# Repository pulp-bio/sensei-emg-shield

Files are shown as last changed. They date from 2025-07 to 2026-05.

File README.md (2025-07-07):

# SENSEI EMG shield

This repository contains the hardware design files for the **SENSEI EMG shield**, a versatile and modular platform designed for Electromyography (EMG) signal acquisition.

## Overview

The **SENSEI EMG Shield** simplifies EMG measurements with a flexible electrode-to-channel mapping system. Different electrode configurations can be rapidly selected by plugging interchangeable channel mapping PCBs directly onto the shield, enabling quick adaptation to different measurement scenarios.

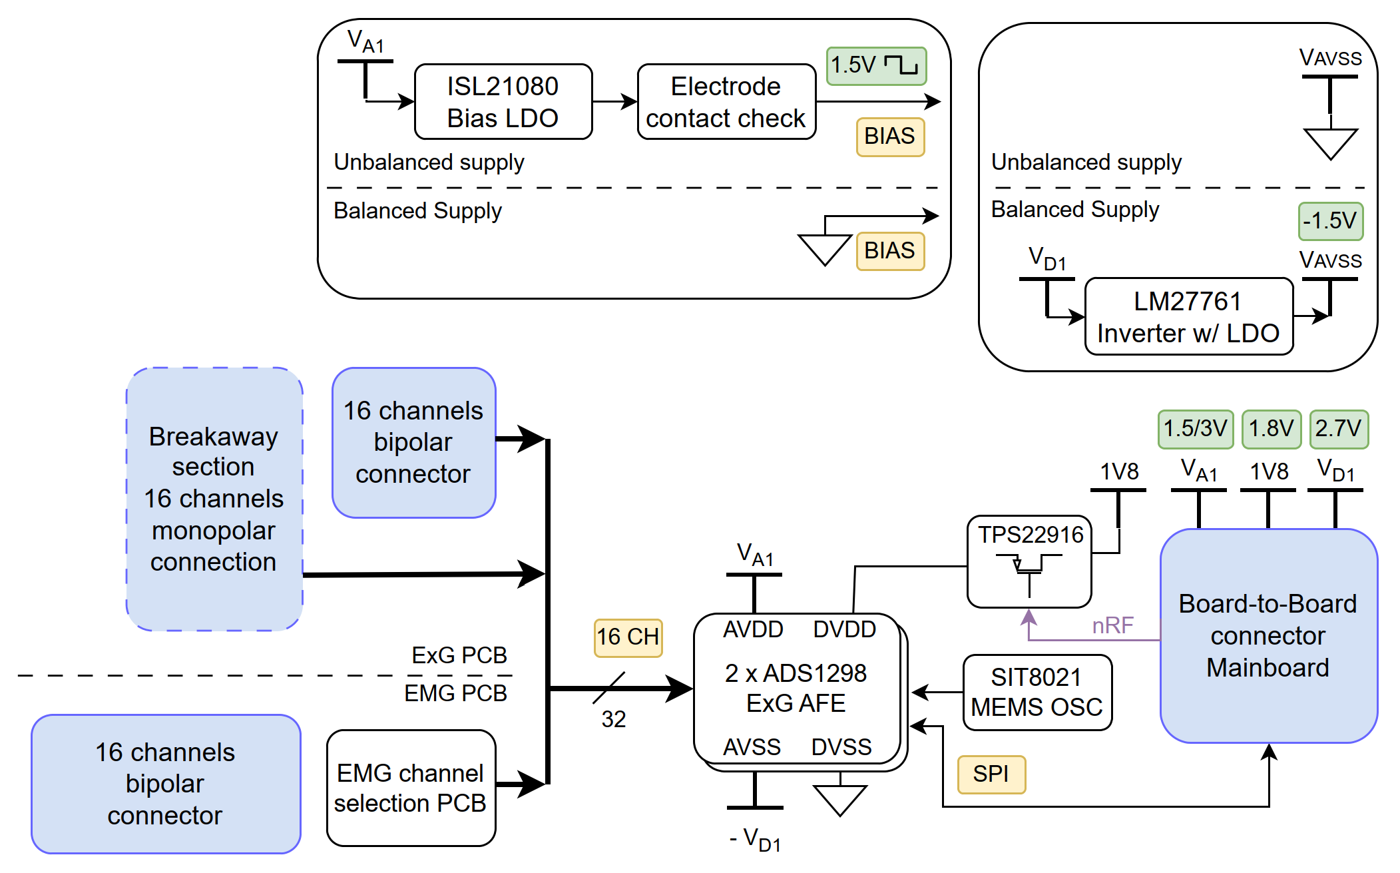
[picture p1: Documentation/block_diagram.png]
Block Diagram


### Key Features
- **16 EMG channels**
- Interchangeable electrode-to-channel mappings:
  - Fully differential
  - Partial electrode sharing
  - Common reference electrode montage
- Easy configuration through swappable channel-mapping PCBs
- Balanced (±1.5 V) analog operation
- Stable MEMS-based clock (±50 ppm accuracy)

## Changelog
A changelog is available in the [Changelog.md](Changelog.md) file, which tracks all major updates and revisions to the board's design and documentation.

## Contributors
- **Sebastian Frey** ([sefrey@iis.ee.ethz.ch](mailto:sefrey@iis.ee.ethz.ch))

## License
This repository makes use of the following licenses:
- for all *hardware*: Solderpad Hardware License Version 0.51
- for all *images*: Creative Commons Attribution 4.0 International
License][cc-by]

For further information have a look at the license files: `LICENSE.hw`, `LICENSE.images`

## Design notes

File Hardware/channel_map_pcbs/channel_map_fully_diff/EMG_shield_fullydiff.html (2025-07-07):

Altium customize

# Board Information Report

Date: | | 19/01/2025
Time: | | 16:14:43
Elapsed Time: | | 00:00:00
Filename: | | C:\Users\laksh\Desktop\BA\pcb\ExG_shield_fullydiff_pcb\EMG_shield_fullydiff.PcbDoc
Units: | | mmmils

## Contents

Contents

Board Specification

General

Routing

Routing Information

Layer Information

Layer Information

Drill Pairs

Copper Area

Copper Area

Board Holes

Non-Plated Hole Size

Plated Hole Size

Board Slots

Non-Plated Slot Size

Plated Slot Size

Board Square Holes

Non-Plated Square Hole Size

Plated Square Hole Size

Other

Top Layer Annular Ring Size

Mid Layer Annular Ring Size

Bottom Layer Annular Ring Size

Pad Solder Mask

Pad Paste Mask

Pad Pwr/Gnd Expansion

Pad Relief Conductor Width

Pad Relief Air Gap

Pad Relief Entries

Via Solder Mask

Via Pwr/Gnd Expansion

Track Width

Arc Line Width

Arc Radius

Arc Degrees

Text Height

Text Width

Net Track Width

Net Via Size

## Board Specification

General
Board Size | 19.5322mm x 19.5375mm
Components on board | 2

Back to top

## Routing

Routing Information
Routing completion | 100.00%
Connections | 40
Connections routed | 40
Connections remaining | 0

Back to top

## Layer Information

Layer | Arcs | Pads | Vias | Tracks | Texts | Fills | Regions | ComponentBodies
Top Layer | 0 | 90 | 0 | 289 | 0 | 0 | 7 | 0
SIG1 | 0 | 0 | 0 | 174 | 0 | 0 | 9 | 0
SIG2 | 0 | 0 | 0 | 93 | 0 | 0 | 7 | 0
Bottom Layer | 0 | 0 | 0 | 60 | 0 | 0 | 7 | 0
Mechanical 1 | 0 | 0 | 0 | 0 | 1 | 0 | 0 | 2
Top 3D Body | 0 | 0 | 0 | 0 | 0 | 0 | 0 | 0
Top Courtyard | 0 | 0 | 0 | 0 | 0 | 0 | 0 | 0
Top Assembly | 0 | 0 | 0 | 0 | 0 | 0 | 0 | 0
Mechanical 13 | 2 | 0 | 0 | 8 | 0 | 0 | 0 | 0
Mechanical 15 | 0 | 0 | 0 | 8 | 0 | 0 | 2 | 0
Top Component Center | 0 | 0 | 0 | 0 | 0 | 0 | 0 | 0
Bottom Assembly | 0 | 0 | 0 | 0 | 0 | 0 | 0 | 0
Bottom Courtyard | 0 | 0 | 0 | 0 | 0 | 0 | 0 | 0
Bottom 3D Body | 0 | 0 | 0 | 0 | 0 | 0 | 0 | 0
Bottom Component Center | 0 | 0 | 0 | 0 | 0 | 0 | 0 | 0
Top Overlay | 0 | 0 | 0 | 12 | 4 | 0 | 0 | 0
Board Layer Stack Bottom Overlay | 3 | 0 | 0 | 0 | 2 | 0 | 7 | 0
Top Paste | 0 | 0 | 0 | 0 | 0 | 0 | 0 | 0
Bottom Paste | 0 | 0 | 0 | 0 | 0 | 0 | 0 | 0
Top Solder | 0 | 0 | 0 | 0 | 0 | 0 | 0 | 0
Board Layer Stack Bottom Solder | 0 | 0 | 0 | 0 | 0 | 0 | 0 | 0
Drill Guide | 0 | 0 | 0 | 0 | 0 | 0 | 0 | 0
Keep-Out Layer | 0 | 0 | 0 | 0 | 0 | 0 | 0 | 0
Drill Drawing | 0 | 0 | 0 | 0 | 0 | 0 | 0 | 0
Multi-Layer | 0 | 0 | 60 | 0 | 0 | 0 | 1 | 0
Total | 5 | 90 | 60 | 644 | 7 | 0 | 40 | 2

Back to top

Drill Pairs | Vias
Top Layer - Bottom Layer | 60
Total | 60

Back to top

## Copper Area

Layer | Sq.In. | Sq.MM. | Percent of layer
Top Layer | 0.453 | 292.274 | 77%
SIG1 | 0.454 | 292.964 | 77%
SIG2 | 0.495 | 319.507 | 84%
Bottom Layer | 0.508 | 327.491 | 86%
Total | 1.91 | 1232.236

Back to top

## Board Holes

Non-Plated Hole Size | Pads | Vias
Total | 0 | 0

Back to top

Plated Hole Size | Pads | Vias
0mm | 90 | 0
0.2mm | 0 | 60
Total | 90 | 60

Back to top

## Board Slots

Non-Plated Slot Size / Length | Pads
Total | 0

Back to top

Plated Slot Size / Length | Pads
Total | 0

Back to top

## Board Square Holes

Non-Plated Square Hole Size | Pads
Total | 0

Back to top

Plated Square Hole Size | Pads
Total | 0

Back to top

## Other

Top Layer Annular Ring Size | Count
0.15mm | 60
Total | 60

Back to top

Mid Layer Annular Ring Size | Count
0.15mm | 60
Total | 60

Back to top

Bottom Layer Annular Ring Size | Count
0.15mm | 60
Total | 60

Back to top

Pad Solder Mask | Count
0mm | 90
Total | 90

Back to top

Pad Paste Mask | Count
0mm | 90
Total | 90

Back to top

Pad Pwr/Gnd Expansion | Count
0.1016mm | 90
Total | 90

Back to top

Pad Relief Conductor Width | Count
0.1016mm | 90
Total | 90

Back to top

Pad Relief Air Gap | Count
0.1016mm | 90
Total | 90

Back to top

Pad Relief Entries | Count
4 | 90
Total | 90

Back to top

Via Solder Mask | Count
0.075mm | 60
Total | 60

Back to top

Via Pwr/Gnd Expansion | Count
0.1016mm | 60
Total | 60

Back to top

Track Width | Count
0.0254mm | 8
0.1524mm | 20
0.2mm | 605
0.5mm | 11
Total | 644

Back to top

Arc Line Width | Count
0.1472mm | 2
0.1636mm | 1
0.508mm | 2
Total | 5

Back to top

Arc Radius | Count
0.0008mm | 3
0.381mm | 2
Total | 5

Back to top

Arc Degrees | Count
360 | 5
Total | 5

Back to top

Text Height | Count
1.2mm | 2
1.524mm | 5
Total | 7

Back to top

Text Width | Count
0.15mm | 1
0.254mm | 6
Total | 7

Back to top

Net Track Width | Count
0.1016mm | 37
Total | 37

Back to top

Net Via Size | Count
0.35mm | 37
Total | 37

Back to top

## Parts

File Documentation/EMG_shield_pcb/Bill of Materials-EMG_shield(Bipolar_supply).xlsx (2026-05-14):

Line # | Name | Description | Designator | Quantity | Comment
 | CL05A104KA5NNNC | Cap Ceramic 100nF 25V X5R ±10% SMD 0402 +85°C Paper T/R | C1, C3, C4, C7, C10, C15, C17, C18, C22, C25, C32, C33, C34, C40, C41 | 15
 | CL05A105KP5NNNC | Cap Ceramic 1uF 10V X5R ±10% SMD 0402 +85°C Paper T/R | C2, C5, C6, C9, C11, C12, C16, C19, C20, C24, C26, C27, C37, C39, C42 | 15
 | CL05A106MP8NUB8 | Cap Ceramic 10uF 10V X5R ±20% SMD 0402 +85°C Paper T/R | C8, C23, C31 | 3
 | 04025C102KAT2A-62 | General Purpose Ceramic Capacitor, 0402, 1nF, 10%, X7R, 15%, 50V | C13, C28 | 2
 | CL05A226MQ5QUNC | Cap Ceramic 22uF 6.3V X5R ±20% SMD 0402 +85°C Paper T/R | C14, C29 | 2
 | GRM155R71H152KA01D |  | C21 | 1
 | CGA2B3X7R1V103K050BB | Cap Ceramic 10nF 35V X7R 10% Pad SMD 0402 +125°C Automotive T/R | C30 | 1
 | GRM155Z71A225KE01D | Chip Multilayer Ceramic Capacitors for General Purpose, 0402, 2.2uF, X7R, 15%, 10%, 10V | C35 | 1
 | CL05A475MP5NRNC | Cap Ceramic 4.7uF 10V X5R ±20% SMD 0402 +85°C Paper T/R | C36, C38 | 2
 | DF40HC(2.5)-40DS-0.4V(51) | 40 Position 0.4mm Pitch Dual Row Vertical Surface Mount (SMT) Pin Socket, 2.5mm Stacking Height | J3 | 1
 | DF40HC(2.5)-50DS-0.4V(51) | 50 Position 0.4mm Pitch Dual Row Vertical Surface Mount (SMT) Pin Socket, 2.5mm Stacking Height | J4 | 1
 | DF40C-40DP-0.4V(51) | 50 Position 0.4mm Pitch Dual Row Vertical Surface Mount (SMT) Receptacle | J5, J25 | 2
 | DF40C-50DP-0.4V(51) | 50 Position 0.4mm Pitch Dual Row Vertical Surface Mount (SMT) Receptacle, | J6, J24 | 2
 | PMSS3906,115 | PNP Switching Transistor | Q1 | 1
 | MCS04020C1004FE000 | RES SMD 1M OHM 1% 1/10W 0402 | R1 | 1
 | RT0402BRD0745K3L | RES 45.3K OHM 1/16W .1% SMD 0402 | R2 | 1
 | RN73R1ETTP2003B25 | 200kΩ ±0.1% 0.063W, 1/16W Chip Resistor 0402 (1005 Metric) Moisture Resistant Thin Film | R3 | 1
 | RC0402FR-070RL | RES SMD 0 OHM JUMPER 1/16W 0402 | R4, R10, R11, R12, R13, R14, R33 | 7
 | RT0402FRE074K7L | RES 4.70K OHM 1/16W 1% SMD 0402 | R5 | 1
 | TNPW040214K2BEED | RES 14.2K OHM 1/16W 1% SMD 0402 | R6 | 1
 | RT0402BRD076K34L | RES 6.34K OHM 1/16W 1% SMD 0402 | R7 | 1
 | RR0510P-563-D | 56kΩ ±0.5% 0.0625W 1/16W Chip Resistor 0402 (1005 Metric) Thin Film | R8 | 1
 | ADS1298RIZXGT | 8-Channel, 24-Bit ADC with Integrated Respiration Impedance and ECG Front End, -40 to 85 degC, 64-pin BGA (ZXG64), Green (RoHS & no Sb/Br) | U1, U2 | 2
 | ISL21080CIH320Z-TK | IC VREF SERIES 0.3% SOT23-3 | U3 | 1
 | LM27761DSGT | IC REG CHARGE PUMP ADJ 8WSON | U4 | 1
 | TPS22916CYFPR | Integrated Circuit | U6 | 1
 | SIT8021AC-J3-18S-2.048000 | MEMS OSC 2.048MHZ LVCMOS | Y1 | 1 | We will send this part

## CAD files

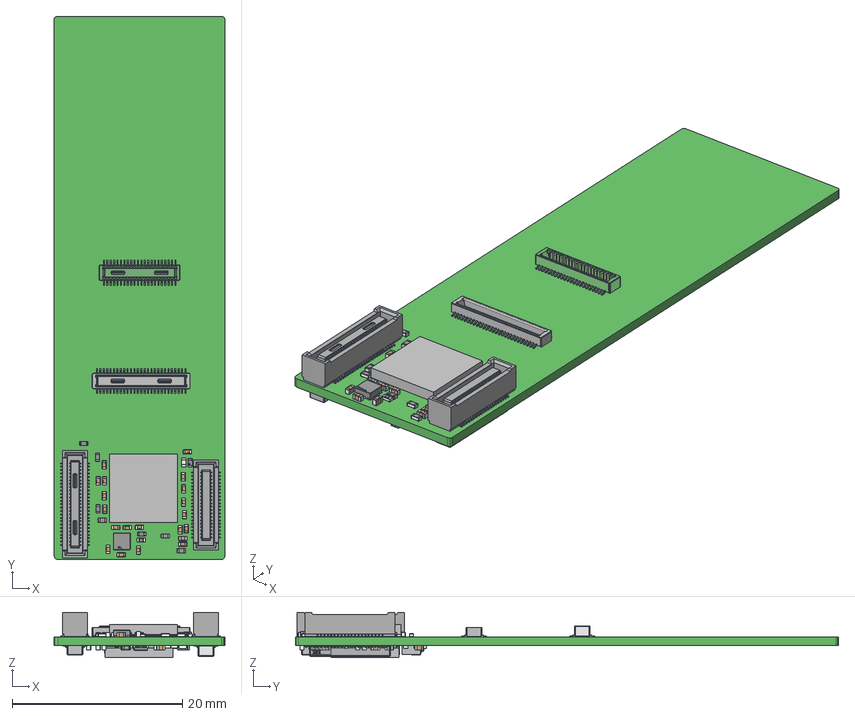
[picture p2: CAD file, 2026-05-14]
Documentation/EMG_shield_pcb/EMG_shield_3D_step.step
20.1 x 63.8 x 5.32 mm
Hirose Electric x 2
Extruded x 6
DF40C-50DP_RGB8421504 x 2
Yageo Logo x 7
terminals x 42
logo x 46
BODY-SON
FRAME-DSG0008A
Texas Logo Yury
Texas Logo Yury - Copy
Balls
0.1mm
Si Time Logo
IC_BODY
IC_LEG x 3
Renesas Logo
circle
Susumu Logo adjustable
pins x 4
top x 2
TDK Logo
DF40HC(3.0)-40DS-0.4V
DF40HC(3.0)-50DS

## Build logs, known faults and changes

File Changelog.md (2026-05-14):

# Changelog

## [1.0.1] (14.05.2026)

### Added

### Changed

- Clock source of ADS1298 is fixed to external oscillator
- Pin from board-to-board connector nRF_P0.05 is not used anymore for clk source selection

## [1.0.0] (03.07.2025)
- Inital version

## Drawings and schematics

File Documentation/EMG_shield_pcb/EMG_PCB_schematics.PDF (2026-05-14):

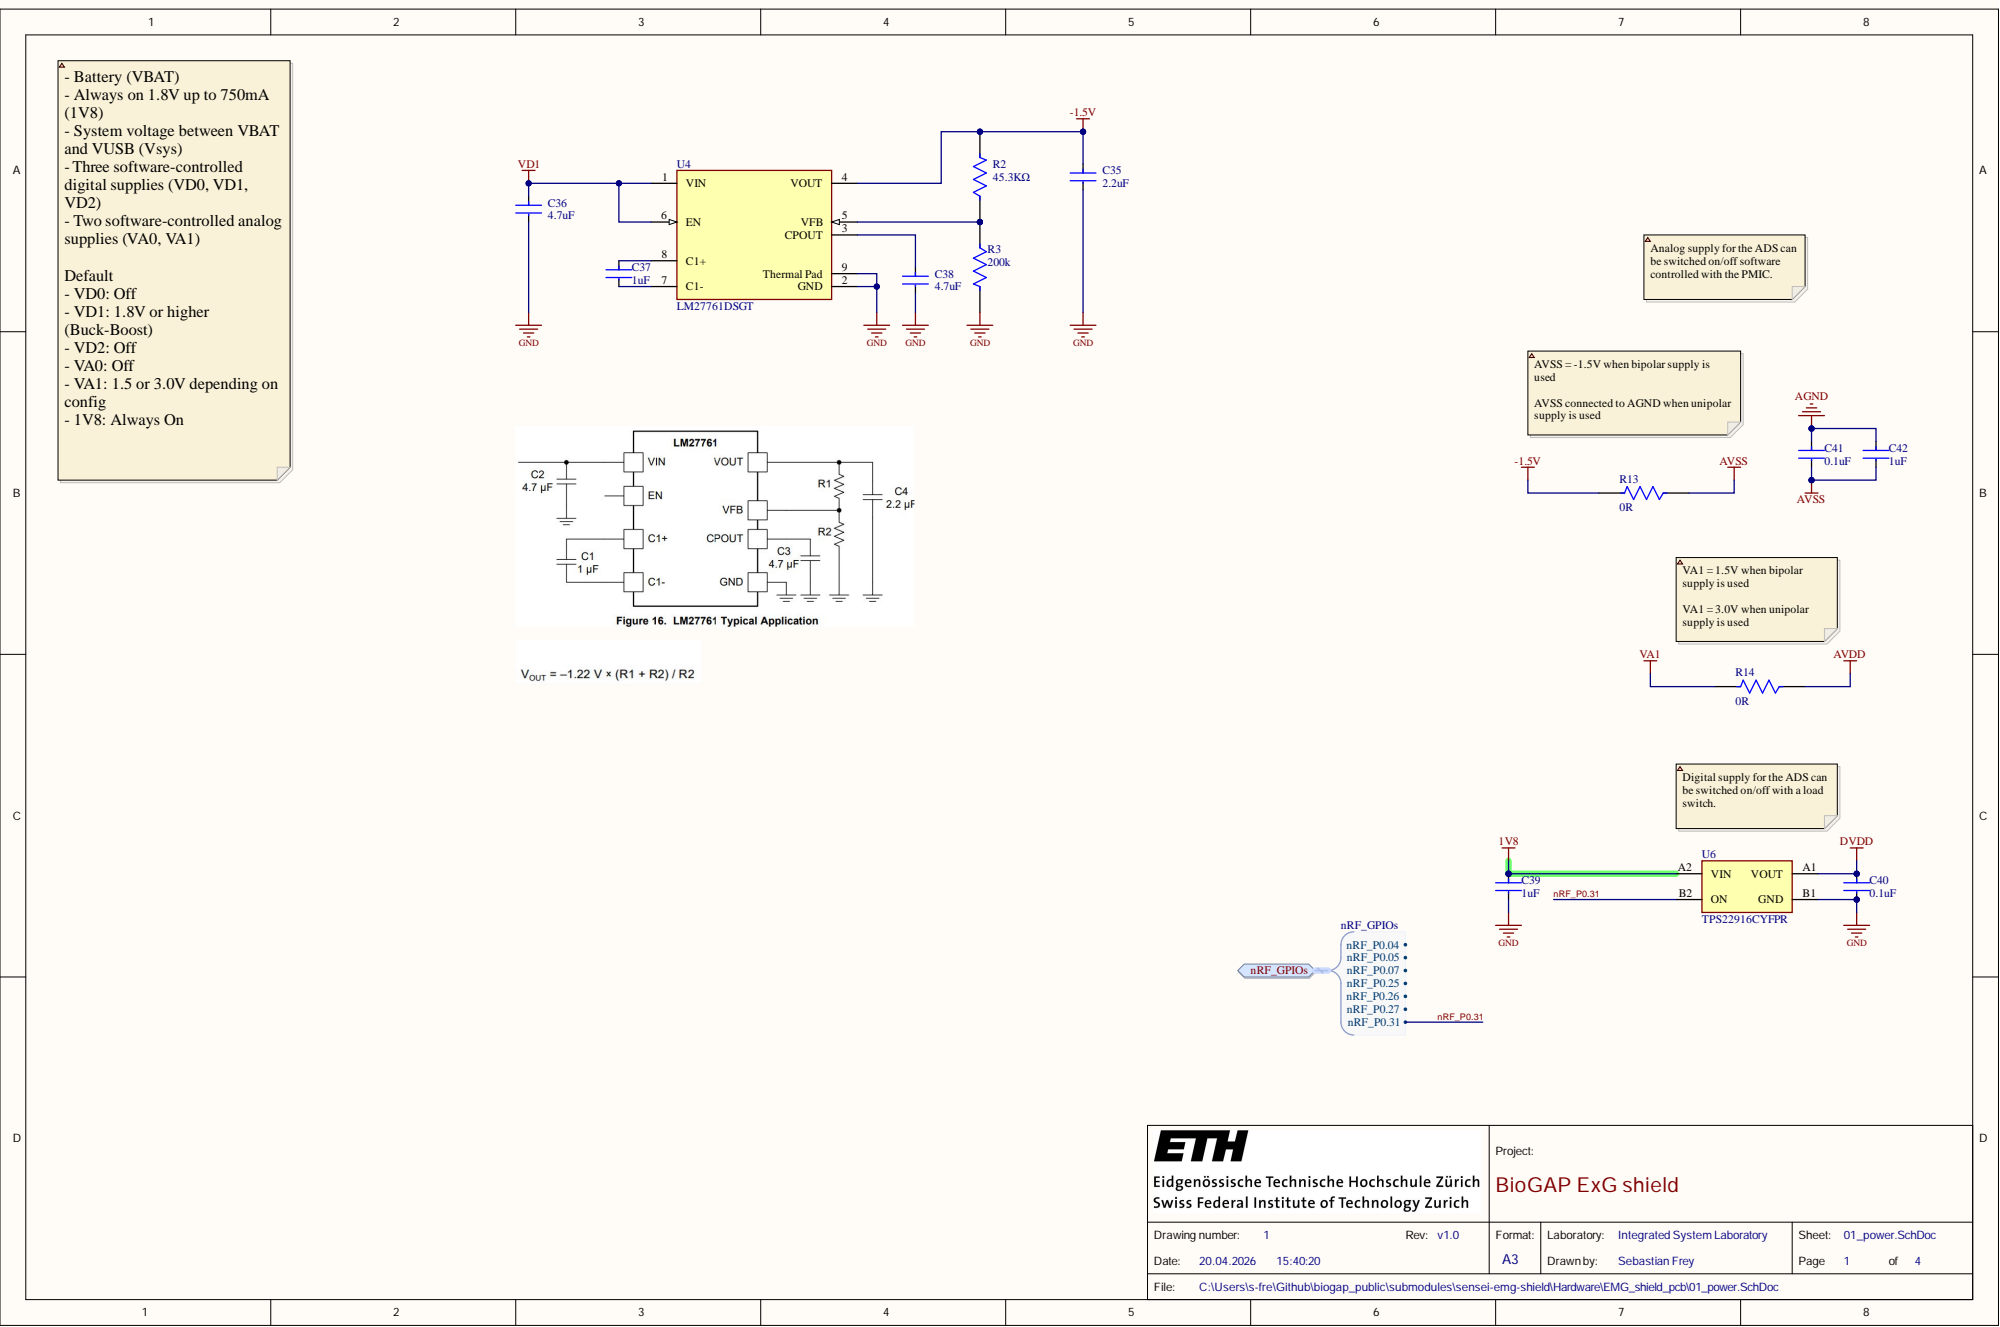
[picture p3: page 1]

- Battery (VBAT)
- Always on 1.8V up to 750mA
- System voltage between VBAT
and VUSB (Vsys)
- Three software-controlled
digital supplies (VD0, VD1,
- Two software-controlled analog
supplies (VA0, VA1)

Analog supply for the ADS can
be switched on/off software
controlled with the PMIC.

AVSS = -1.5V when bipolar supply is
used

AVSS connected to AGND when unipolar
supply is used

Digitalsupply for the ADS can
be switched on/off with a load
switch.

Project: BioGAP ExG shield

Drawing number: 1 Rev: v1.0 Date: 20.04.2026 15:40:20 | Format: A3 | Laboratory: Integrated System Laboratory Drawn by: Sebastian Frey | Sheet: 01_power.SchDoc Page 1 of 4

C:\Users\s-fre\Github\biogap_public\submodules\sensei-emg-shield\Hardware\EMG_shield_pcb\01_power.SchDoc

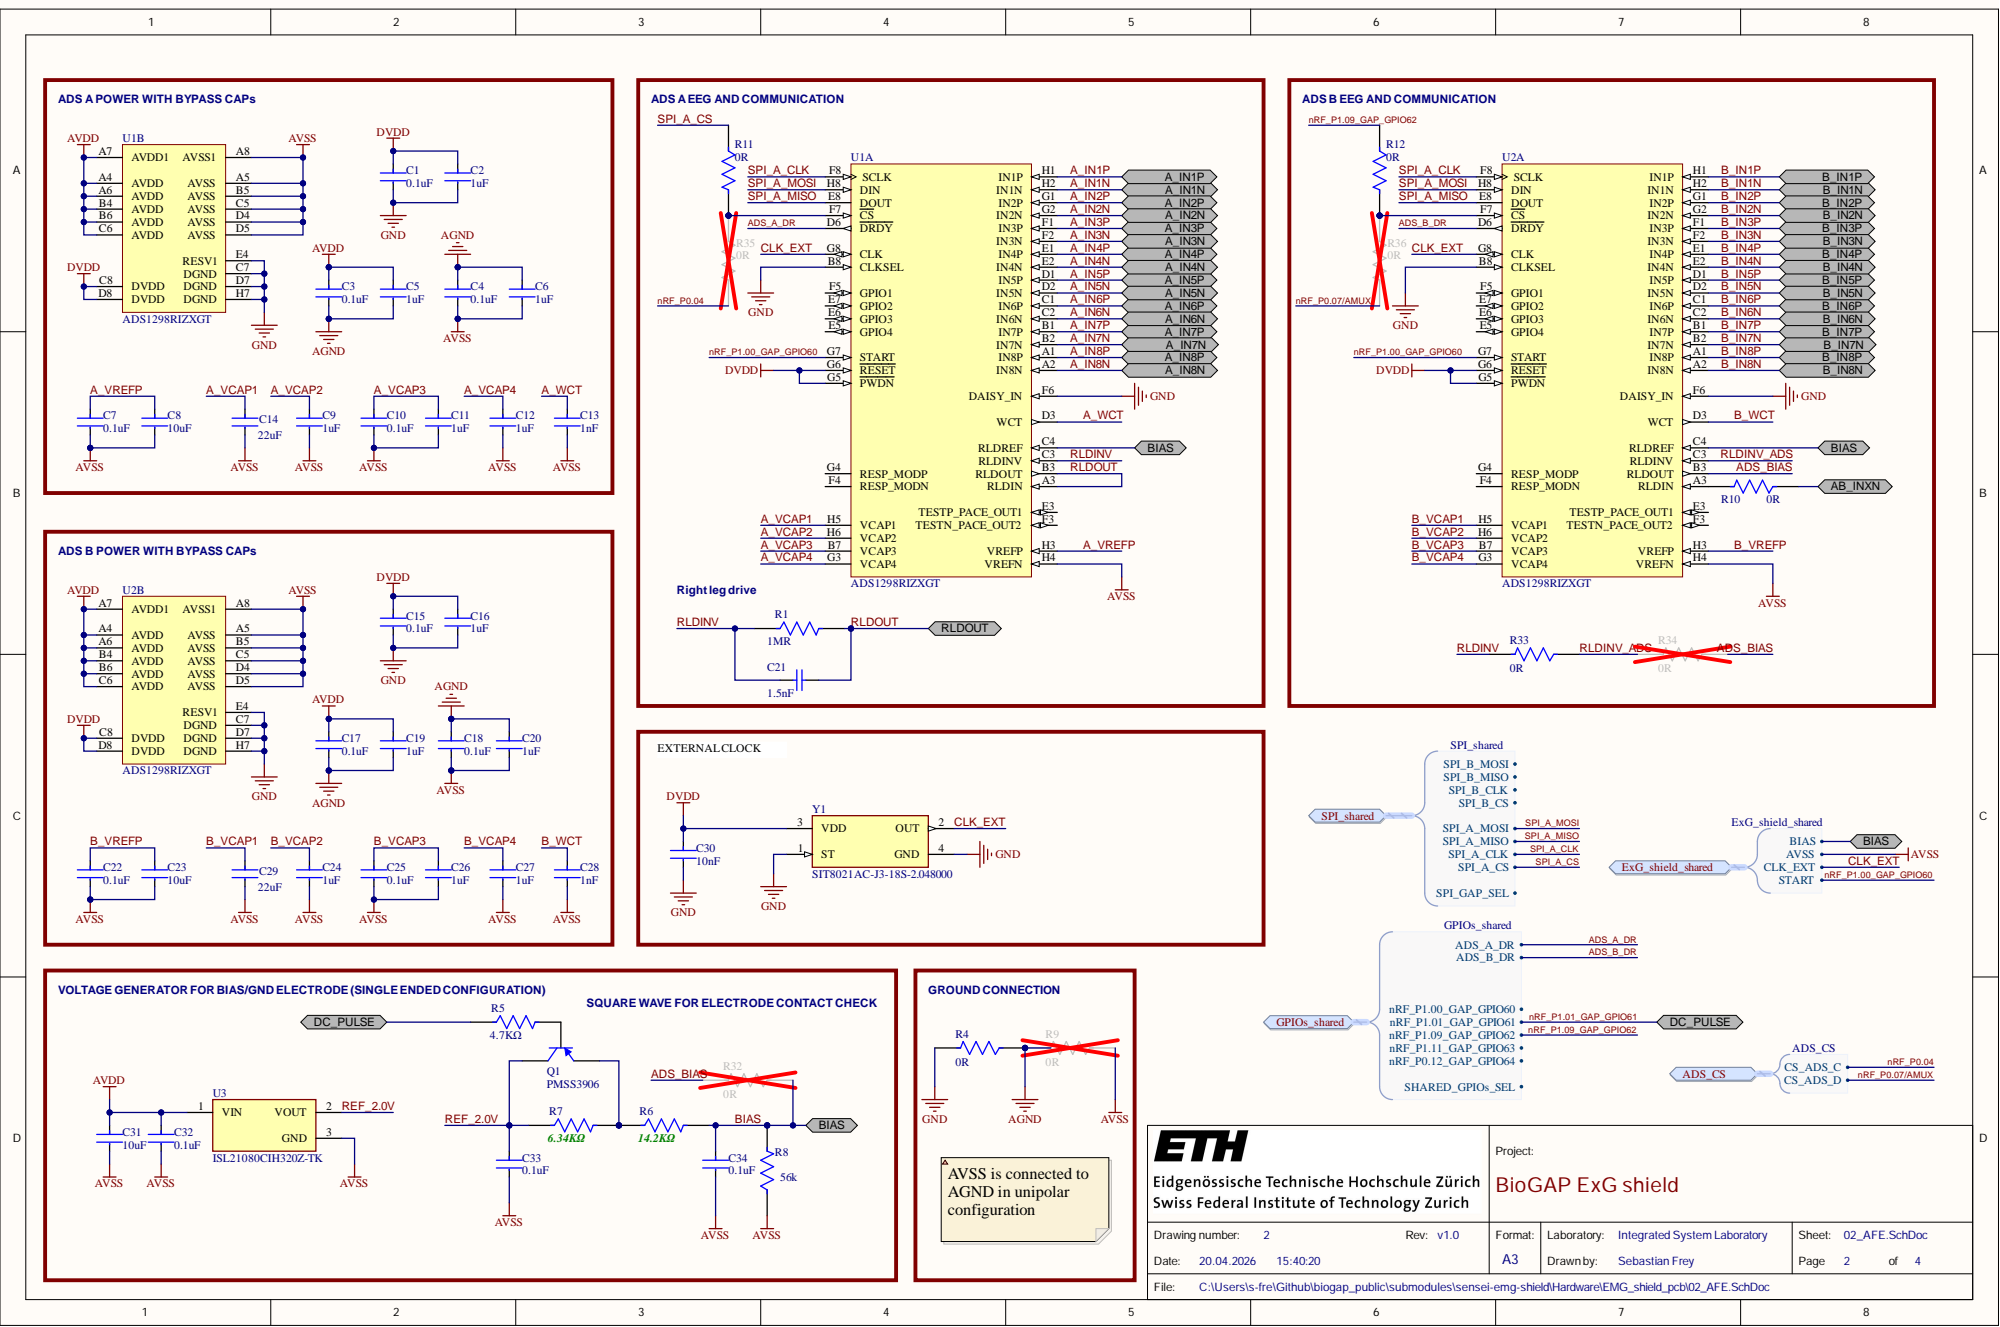
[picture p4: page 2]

ADS A POWER WITH BYPASS CAPs

ADS AEEG AND COMMUNICATION

ADS B EEG AND COMMUNICATION

ADS B POWER WITH BYPASS CAPs

VOLTAGE GENERATOR FOR BIAS/GND ELECTRODE (SINGLE ENDED CONFIGURATION)

SQUARE WAVE FOR ELECTRODE CONTACT CHECK

AVSS is connected to
AGND in unipolar
configuration

C:\Users\s-fre\Github\biogap_public\submodules\sensei-emg-shield\Hardware\EMG_shield_pcb\02_AFE.SchDoc

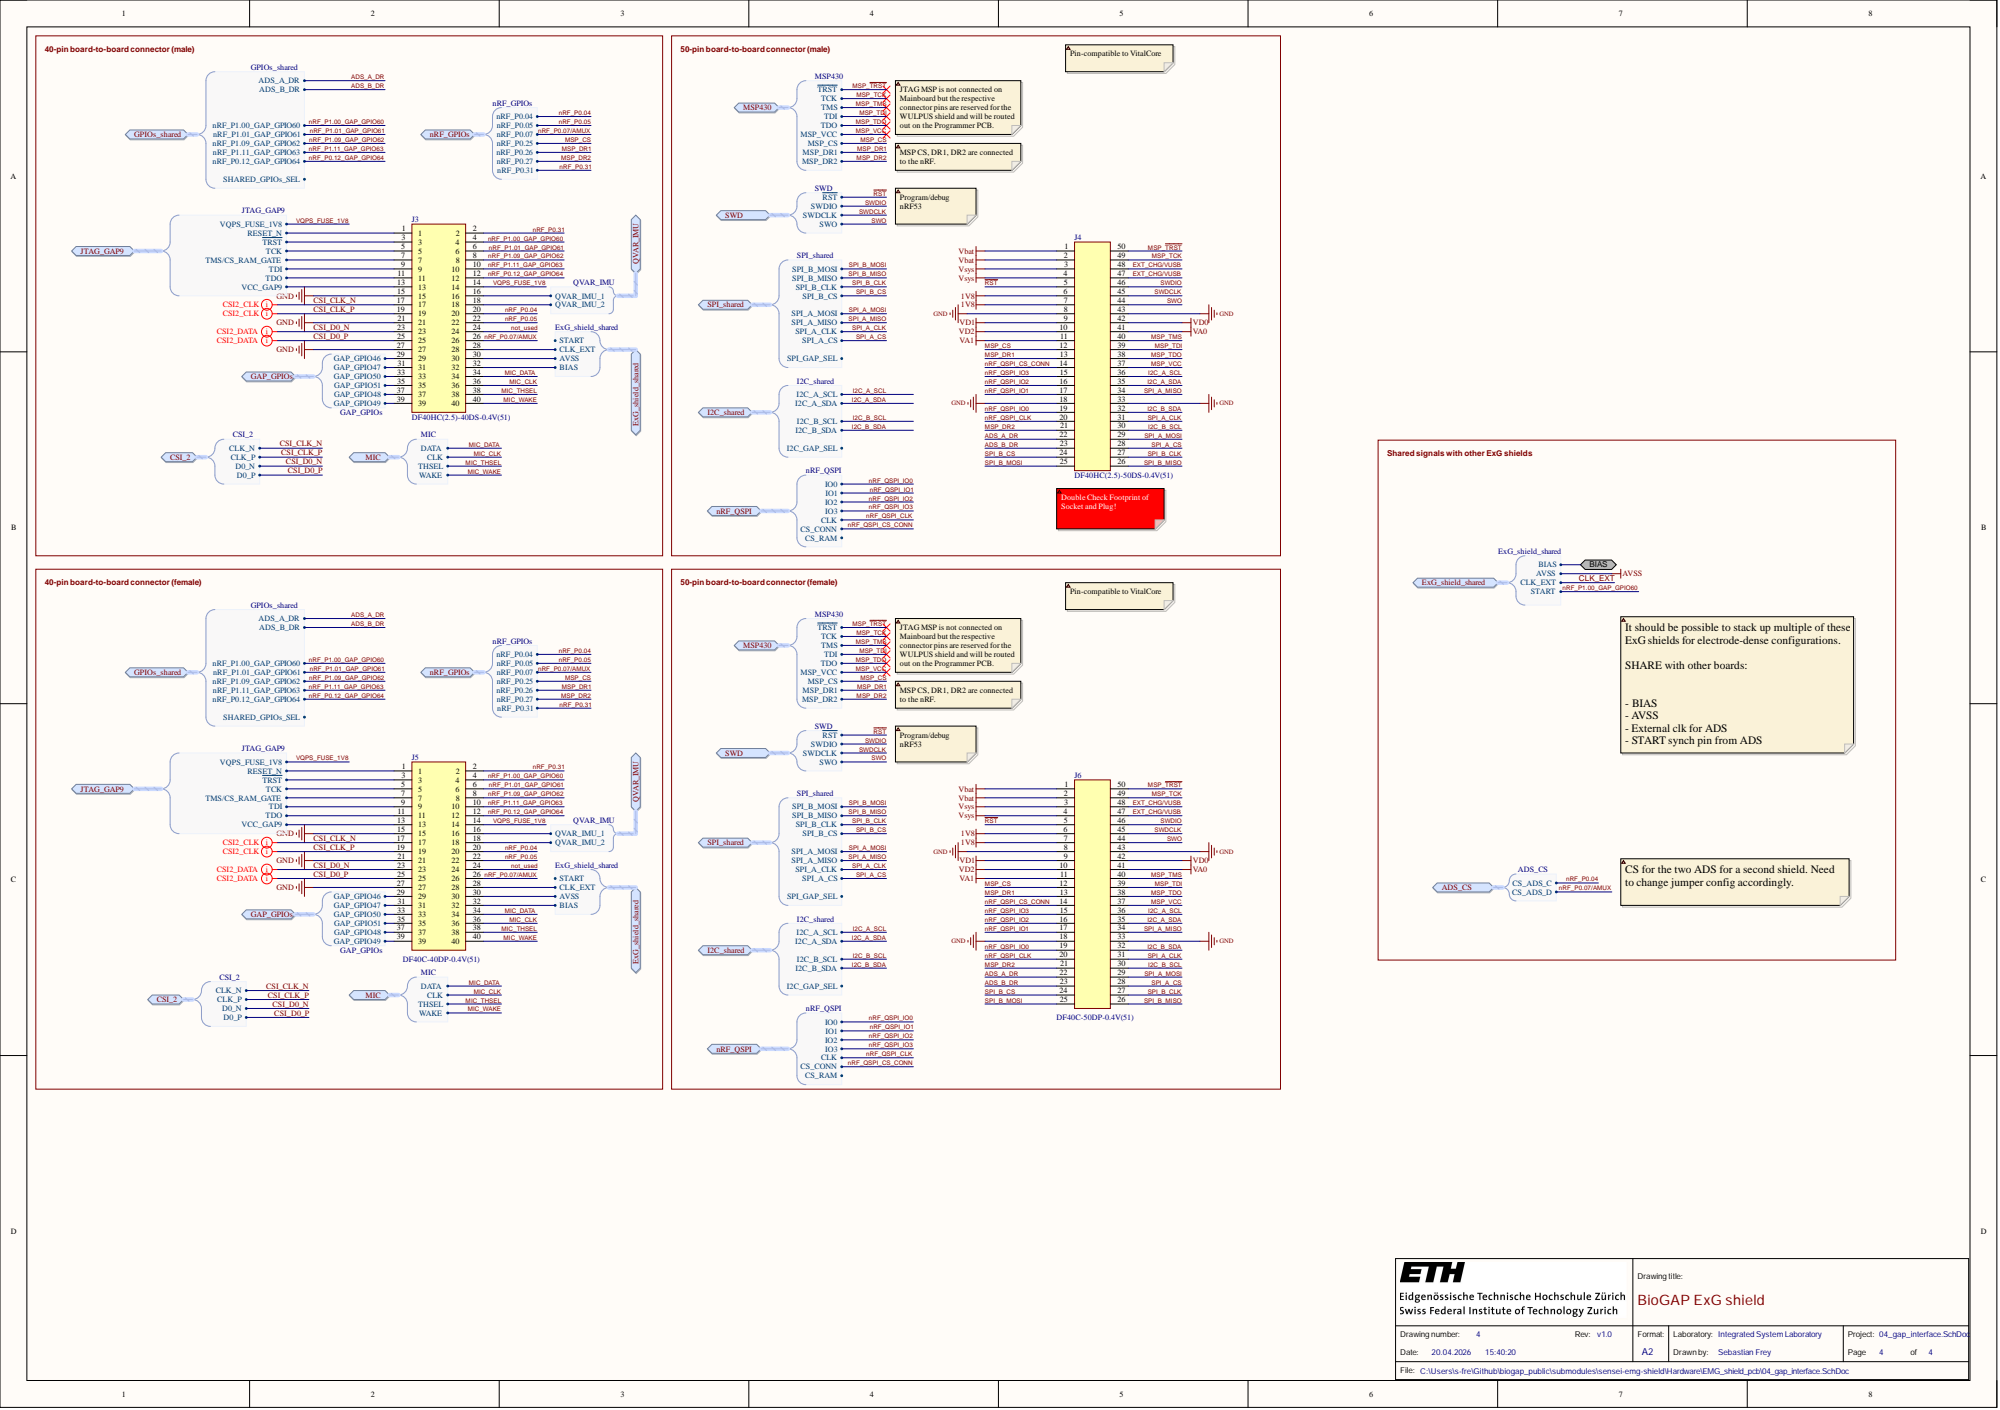
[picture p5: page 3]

40-pin board-to-board connector(male)

50-pin board-to-board connector(male)

Pin-compatible to VitalCore

JTAG MSP is not connected on
Mainboard but the respective
connector pins are reserved for the
WULPUS shield and will be routed
out on the Programmer PCB.

MSP CS, DR1, DR2 are connected
to the nRF.

Shared signals with other ExG shields

Double Check Footprint of
Socket and Plug!

It should be possible to stack up multiple of these
ExG shields for electrode-dense configurations.

SHARE with other boards:

- BIAS
- AVSS
- External clk for ADS
- START synch pin from ADS

CS for the two ADS for a second shield. Need
to change jumper config accordingly.

Drawing title: BioGAP ExG shield

Project: 04_gap_interface.SchDoc Page 4 of 4

C:\Users\s-fre\Github\biogap_public\submodules\sensei-emg-shield\Hardware\EMG_shield_pcb\04_gap_interface.SchDoc

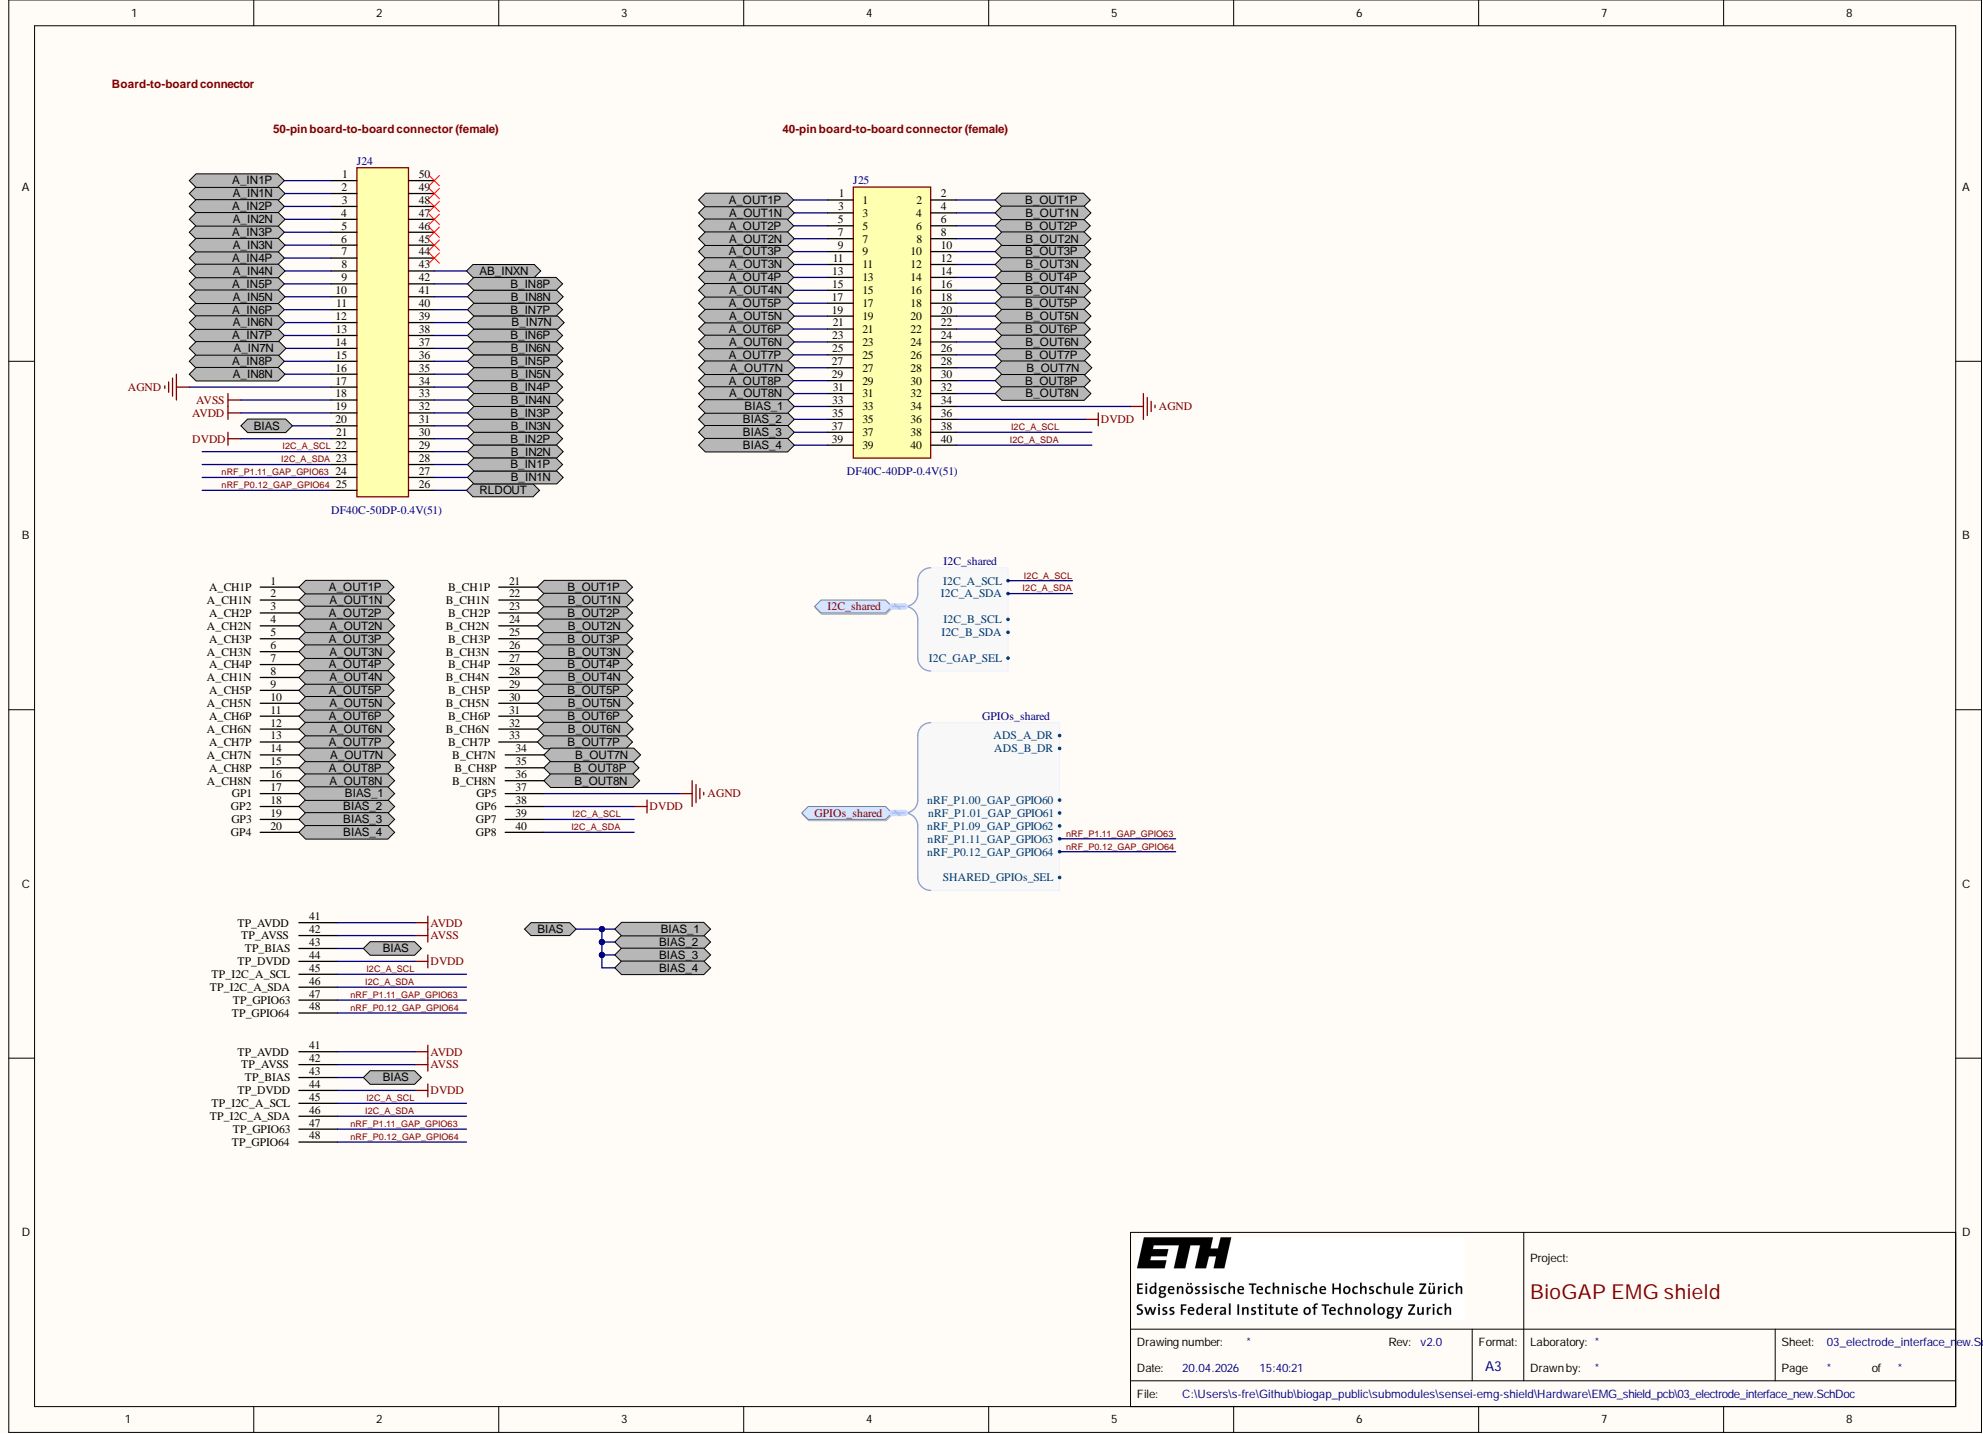
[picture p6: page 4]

Board-to-board connector

Project: BioGAP EMG shield

Drawing number: * Rev: v2.0 | | Laboratory: * * | Page * of *

C:\Users\s-fre\Github\biogap_public\submodules\sensei-emg-shield\Hardware\EMG_shield_pcb\03_electrode_interface_new.SchDoc

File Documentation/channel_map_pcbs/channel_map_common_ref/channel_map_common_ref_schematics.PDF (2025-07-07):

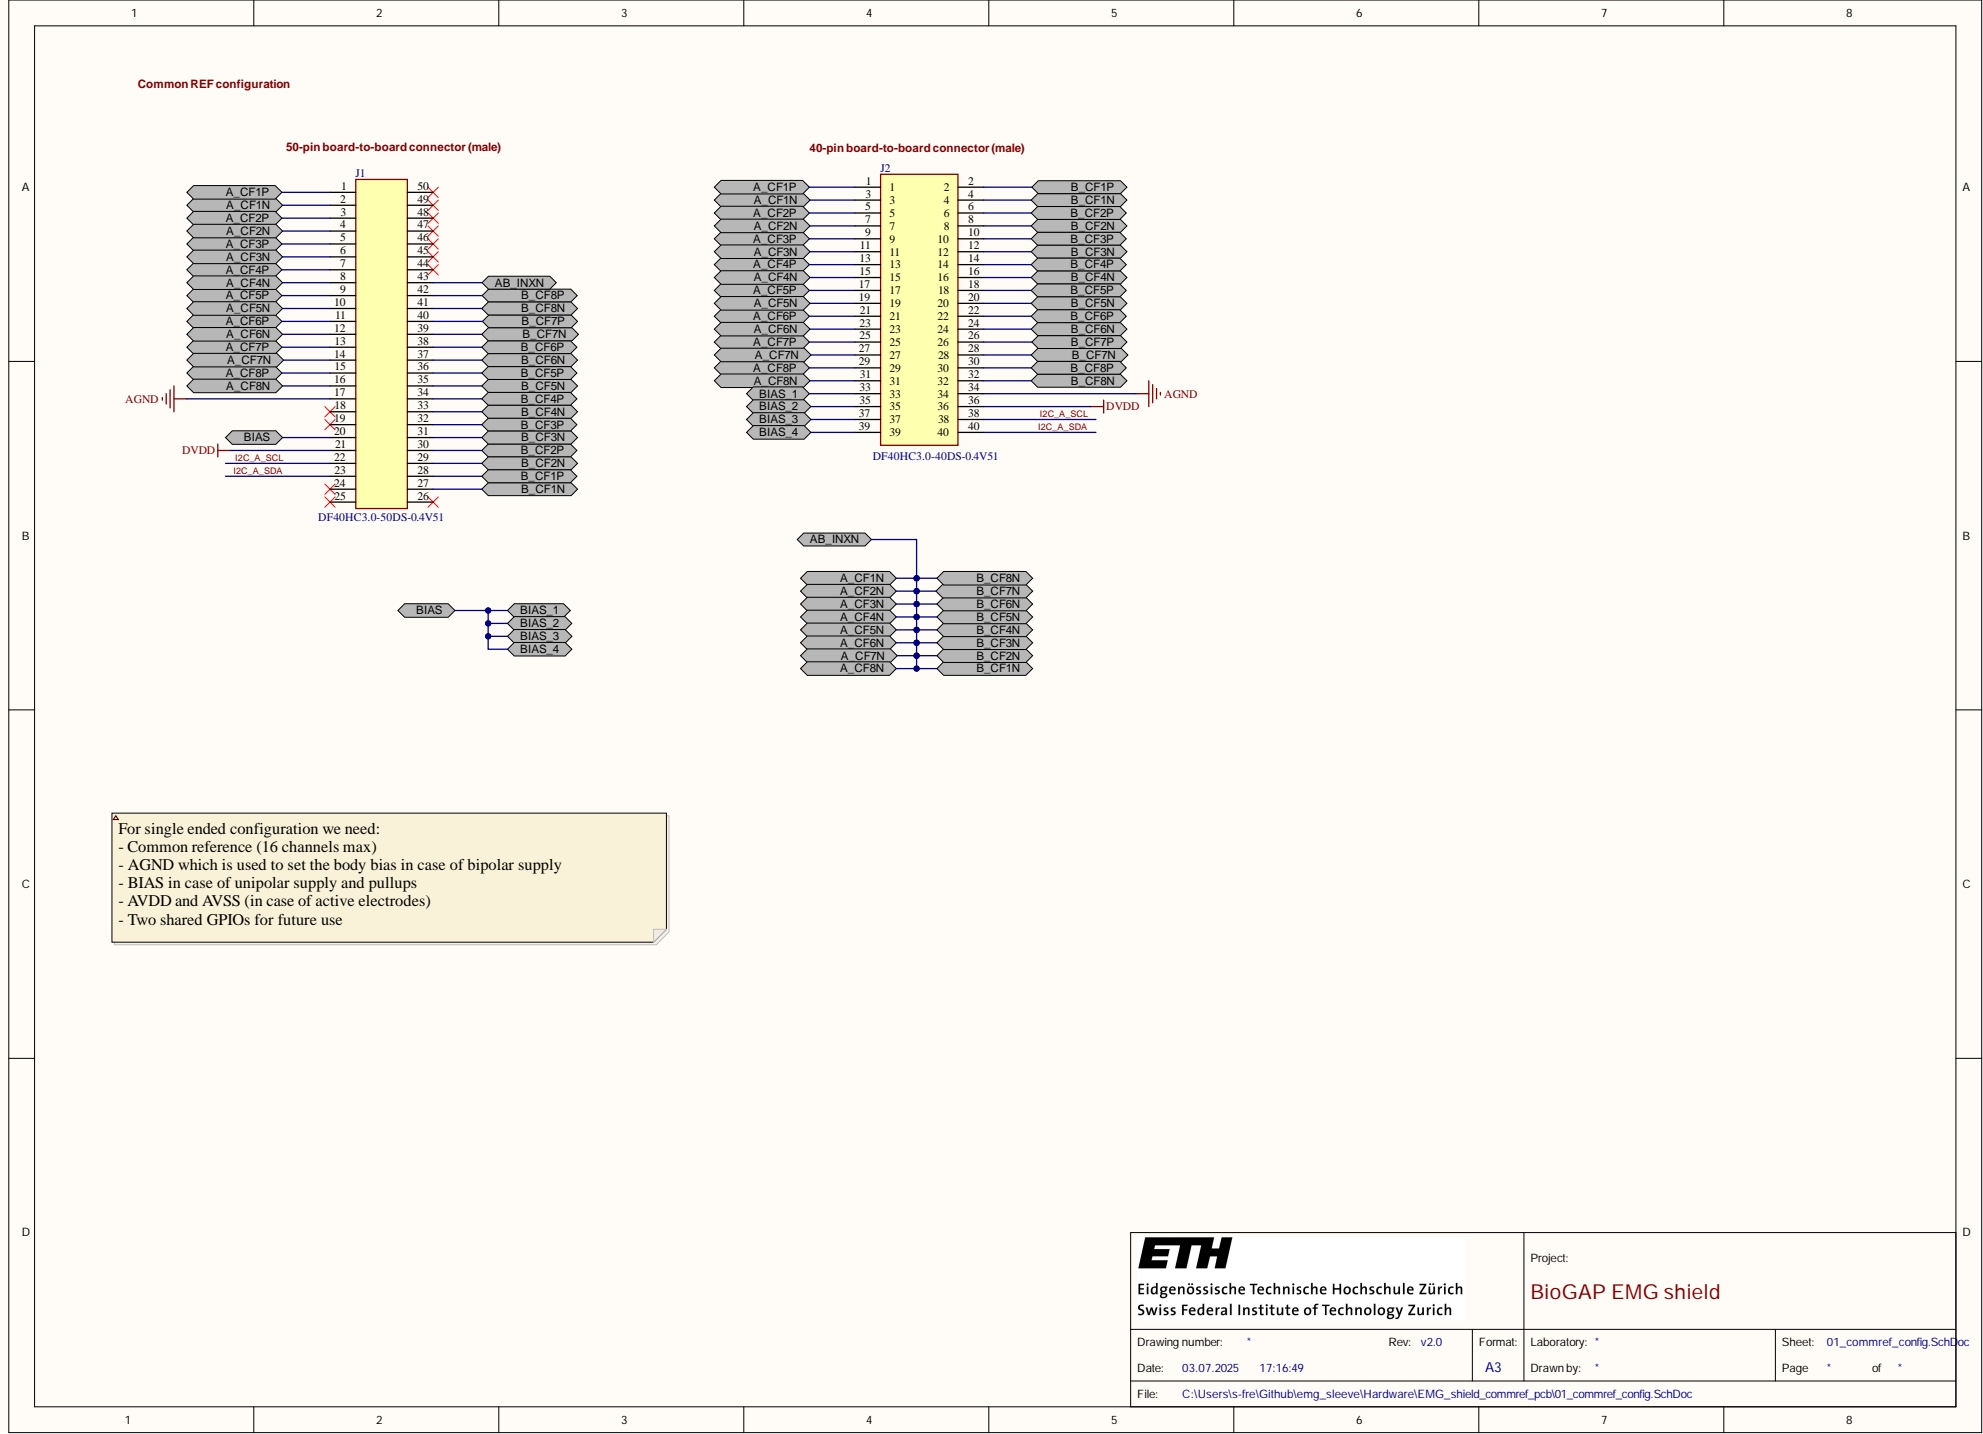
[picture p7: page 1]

in case of unipolar supply and pul

in case of bipolar suppl
lups

AVSS (in case of act
GPI

Os for future use

Proje c t: B i o G A P E M G s h i e l d

Drawing num b e r: * R e v : v 2 . 0 D a te : 03.07. 202 5 17:16 : 49 | Form a t: A 3 | Laborato ry : * Drawn by : * | Shee t: 01_com mref_c o n fi g . S c h D Pag e * of *

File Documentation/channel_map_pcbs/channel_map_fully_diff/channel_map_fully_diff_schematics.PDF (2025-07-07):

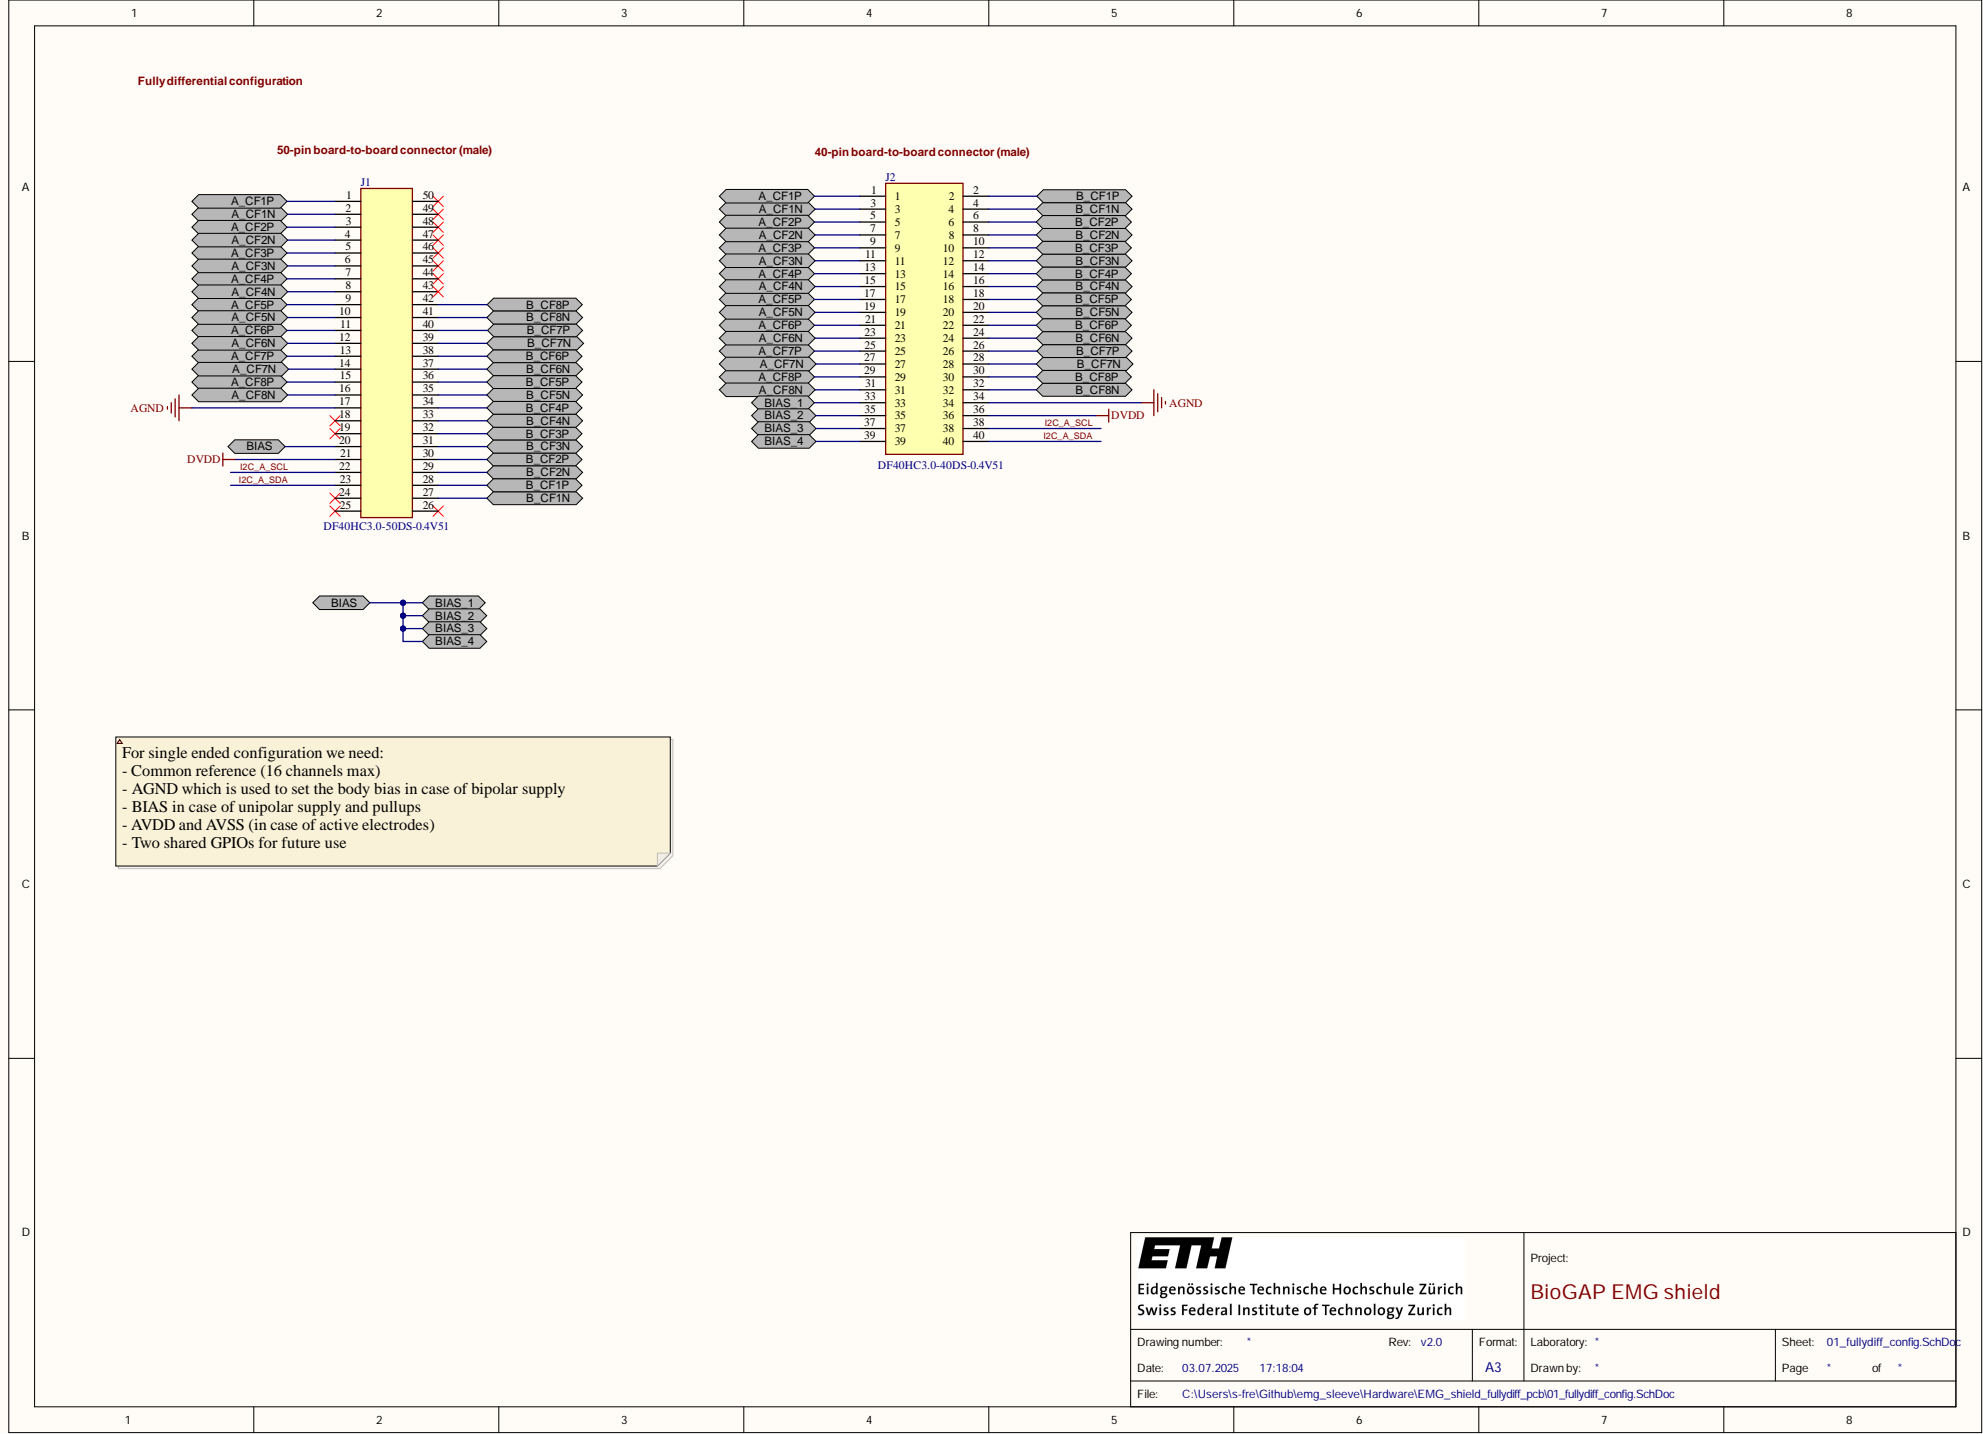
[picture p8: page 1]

in case of unipolar supply and pul

in case of bipolar suppl
lups

AVSS (in case of act
GPI

Os for future use

Proje c t: B i o G A P E MG s h i e l d

Drawing num be r: * R ev : v 2. 0 D a te : 03.07. 2025 17:18: 04 | Form a t: A 3 | Laborato ry : * Drawn by : * | Shee t: 01_fullydiff_con fi g . S c h D oc Pag e * of *

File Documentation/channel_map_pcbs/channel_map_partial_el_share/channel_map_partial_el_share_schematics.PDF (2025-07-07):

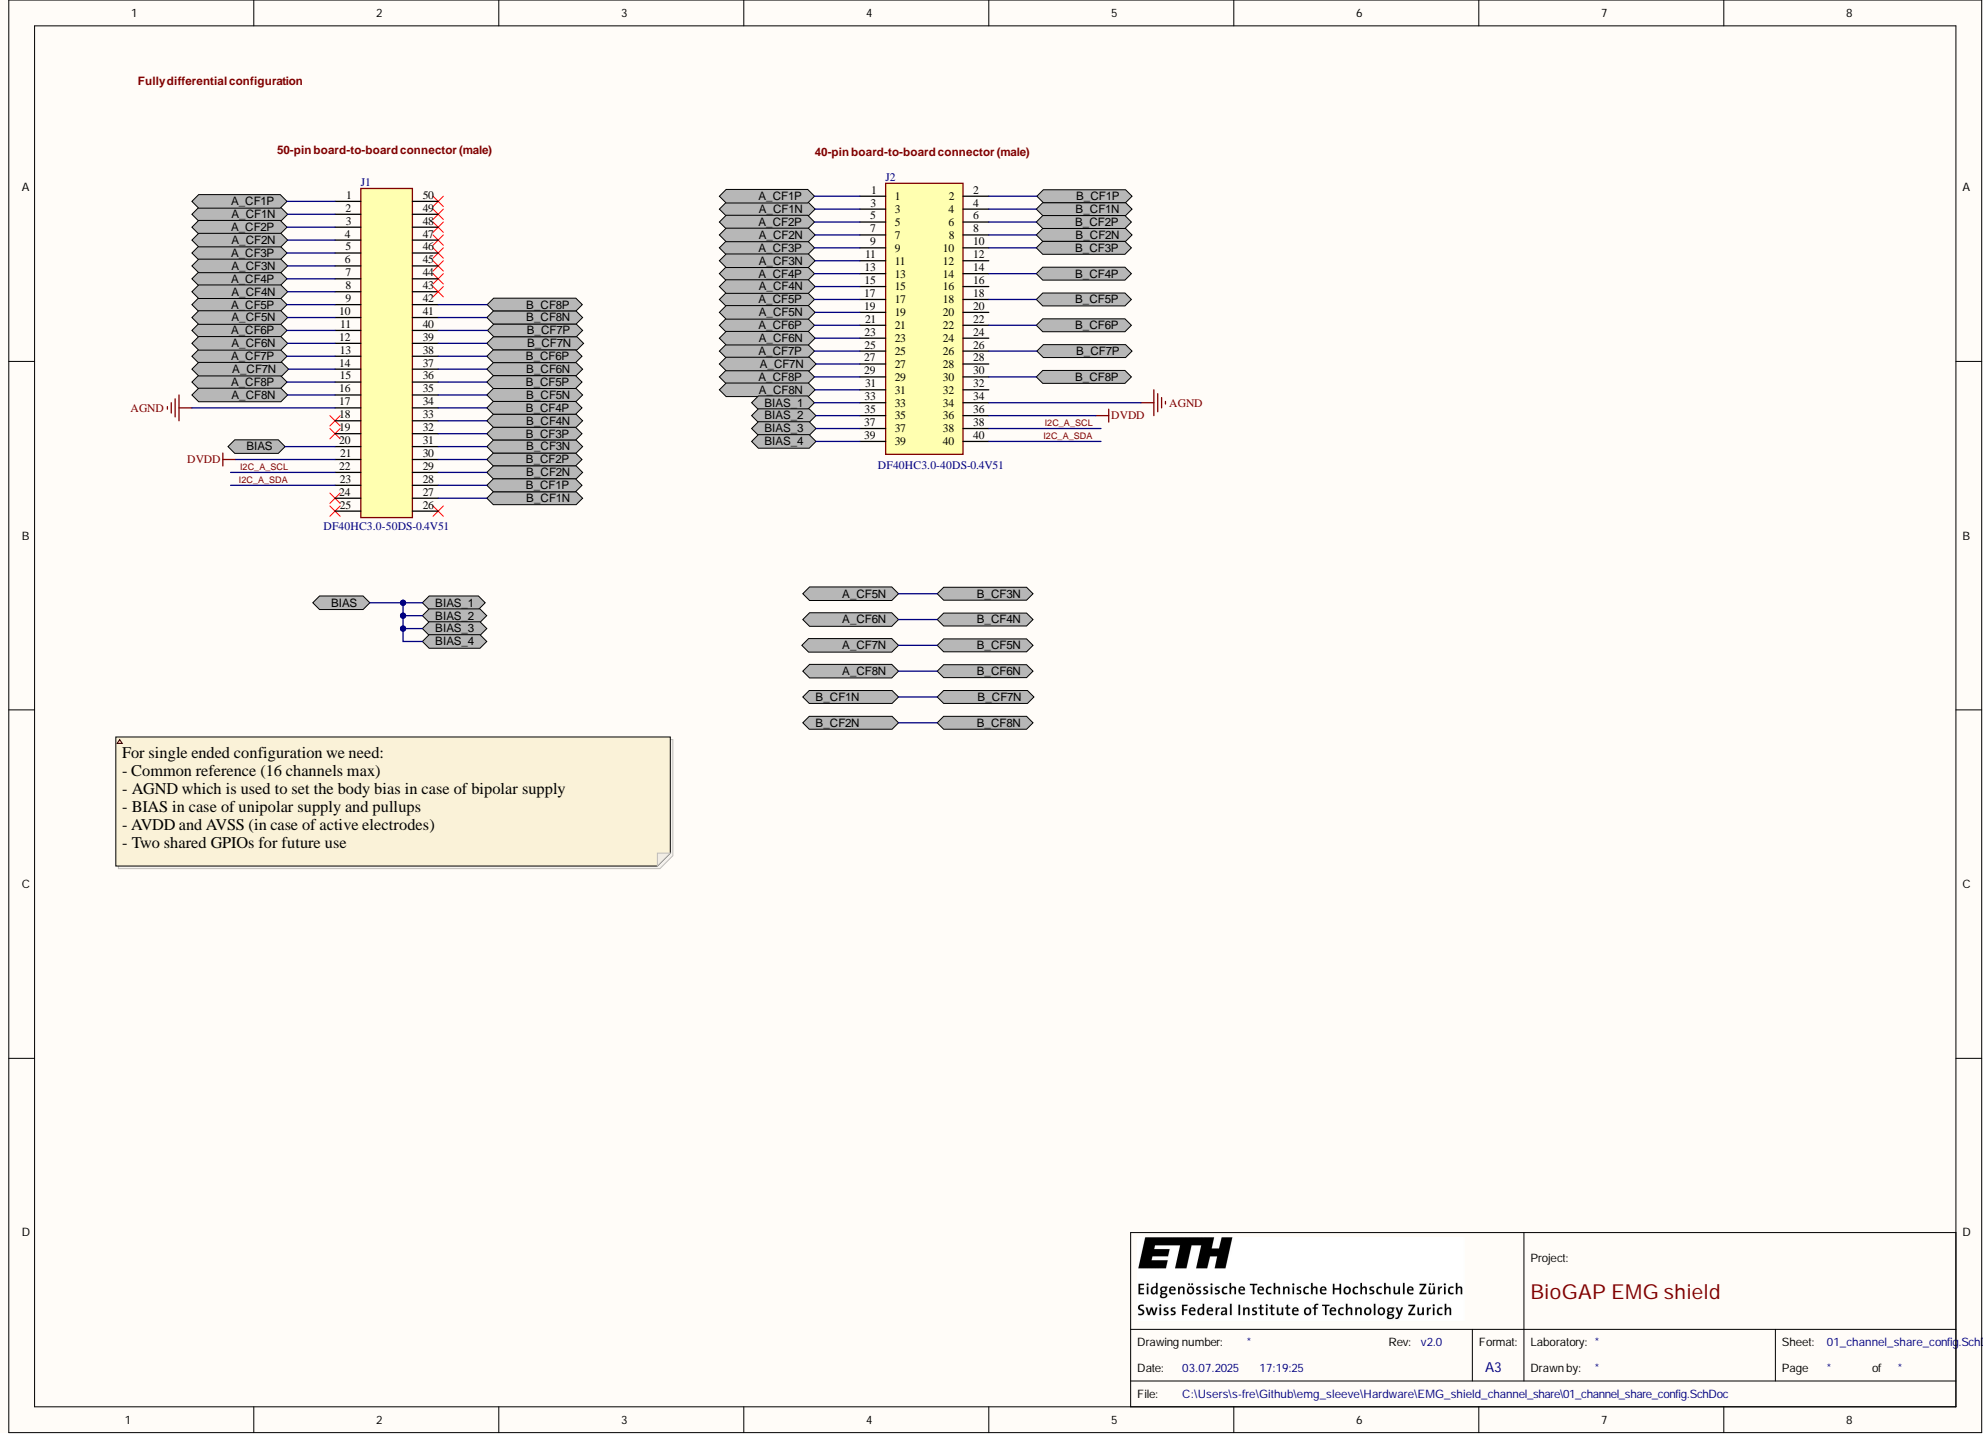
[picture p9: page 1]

in case of unipolar supply and pul

in case of bipolar suppl
lups

AVSS (in case of act
GPI

Os for future use

Proje ct: B i o G A P E MG s h i e l d

Drawing num be r: * R ev : v 2. 0 D a te : 03.07. 2025 17:19: 25 | Forma t: A 3 | Laborato ry : * Drawn by : * | Shee t: 01_channel_share_co nfi g Pag e * of *

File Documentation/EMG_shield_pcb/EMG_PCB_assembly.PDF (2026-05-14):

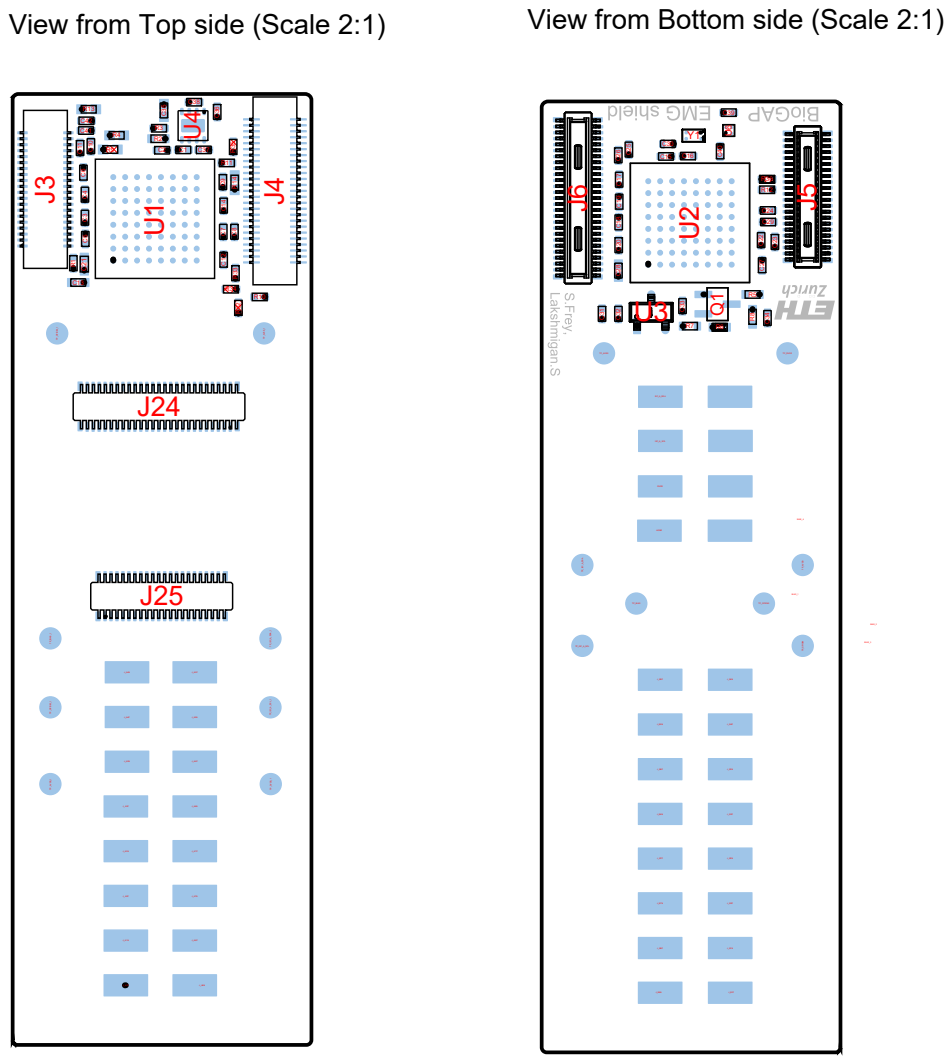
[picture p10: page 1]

View from Top side (Scale 2:1)

View from Bottom side (Scale 2:1)
